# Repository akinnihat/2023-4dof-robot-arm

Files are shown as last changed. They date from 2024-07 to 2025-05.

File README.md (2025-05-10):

# 4 DoF Robot Arm (June 2023)


This is a project I made back in 2023, the last year of my undergraduate education, where I designed, constructed and developed control software of a robotic arm with 4 degrees of freedom.

## Design and Construction


The design of the robot arm was made with Fusion360 (except the gripper, I found it on the internet) and converted to URDF format with the help of [fusion2urdf](https://github.com/syuntoku14/fusion2urdf).
In its construction aluminium with 2mm thickness and 3D printing (PLA, yellow parts in the image above) were used.

## Circuit Design and Electronics


In the electronics of the robot arm:
  - 4 NEMA 17 stepper motors,
  - 4 A4988 stepper motor drivers,
  - 4 100V 100μF capacitors,
  - 2 MG995 servo motors (for gripper control),
  - A power distribution board with 12V and 5V outputs,
  - A 14.8V Li-Po baterry, 
  - Arduino UNO,
  - A laptop was used as the main control computer (originally a Jetson NANO was planned).

## Software and Control


[ROS Noetic](http://wiki.ros.org/noetic) was used on the main computer, [RViz](http://wiki.ros.org/rviz) was used as the control interface and [MoveIt!](https://moveit.ros.org/) was used for kinematics and motion planning. In Arduino, [AccelStepper](https://github.com/waspinator/AccelStepper) was used for stepper motor control and [ros_lib](http://wiki.ros.org/rosserial_arduino/Tutorials/Arduino%20IDE%20Setup) (rosserial) was used for serial communication with ROS.

Installation of ROS Noetic:
```
sudo apt install ros-noetic-desktop
```
Installation of catkin and related build tools:
```
sudo apt install ros-noetic-catkin pyhton3-catkin-tools python3-osrf-pycommon
```
Installation of MoveIt!:
```
sudo apt install ros-noetic-moveit
```
Installation of rosserial for communication between ROS with Arduino over serial (see [ros_lib](http://wiki.ros.org/rosserial_arduino/Tutorials/Arduino%20IDE%20Setup) for Arduino IDE setup for rosserial):
```
sudo apt install ros-noetic-rosserial
sudo apt install ros-noetic-rosserial-arduino
```
Creation of catkin workspace:
```
mkdir catkin-ws
```
Launch of MoveIt! Setup Assistant for robot arm configuration:
```
roslaunch moveit_setup-assistant setup_assistant.launch
```


After configuration of the robot arm, launch of MoveIt! move_group, robot arm hardware interface and serial comminication with Arduino:
```
roslaunch arm_moveit_config move_group.launch
rosrun arm_hardware arm_hardware_node
rosrun rosserial_python serial_node.py _port:=/dev_ttyUSB0 _baud:=115200
```


## Pick and Place

https://github.com/user-attachments/assets/624f2628-760b-4fc2-ad30-154f14537334

## Additional Notes
Some of the flaws made during the development of the project and the points that could have been done better are briefly as follows:
  - Incorrect load capacity calculation and kinematics calculation at the beginning
  - Non-functional 2nd DoF due to design and manufacturing defects
  - No precise control of stepper motors due to lack of feedback mechanism

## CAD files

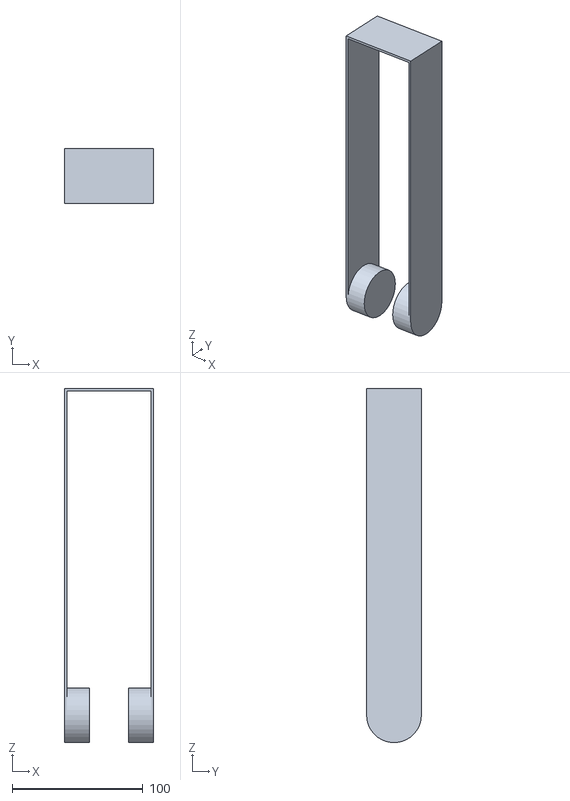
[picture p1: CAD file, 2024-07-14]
catkin_ws/src/arm_description/meshes/D3_1.stl
68.0 x 42.0 x 270.9

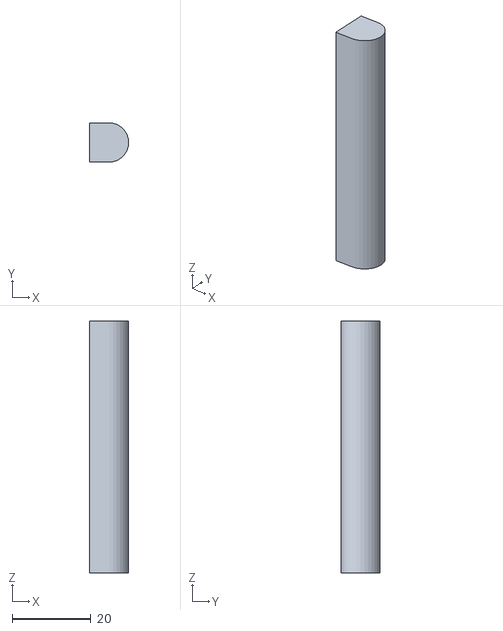
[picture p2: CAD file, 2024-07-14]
catkin_ws/src/arm_description/meshes/Finger_1_1.stl
10.0 x 10.0 x 64.0

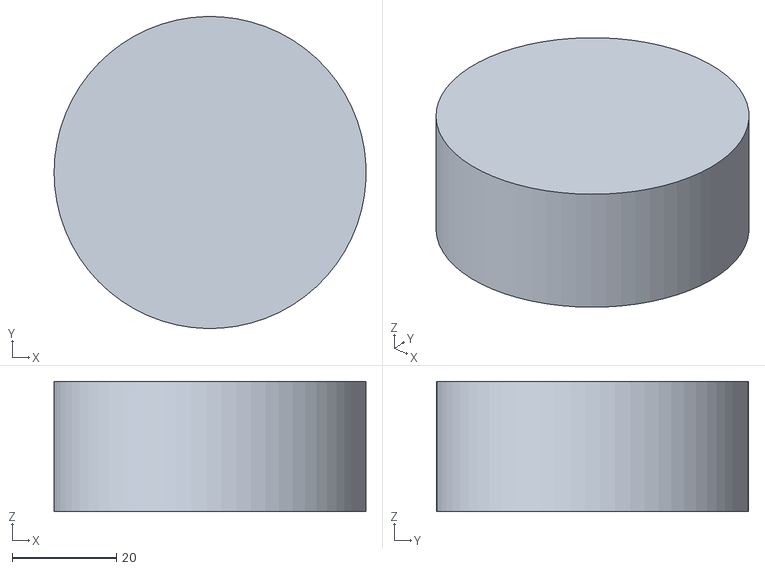
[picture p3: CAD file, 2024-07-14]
catkin_ws/src/arm_description/meshes/base_link.stl
60.0 x 60.0 x 25.0

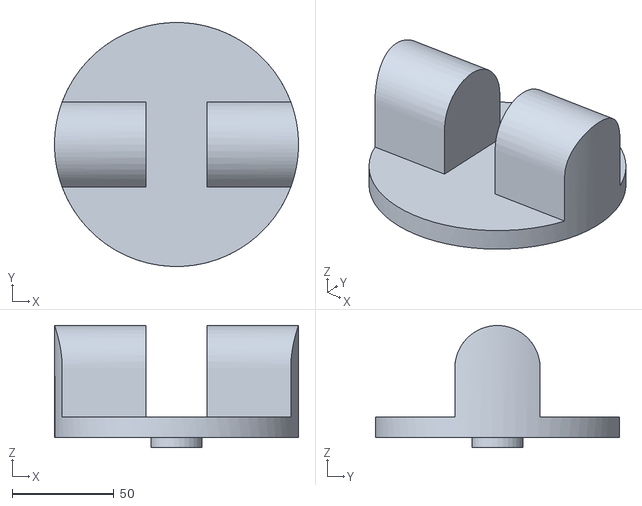
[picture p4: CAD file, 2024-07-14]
catkin_ws/src/arm_description/meshes/Platform_1.stl
120.0 x 120.0 x 60.0

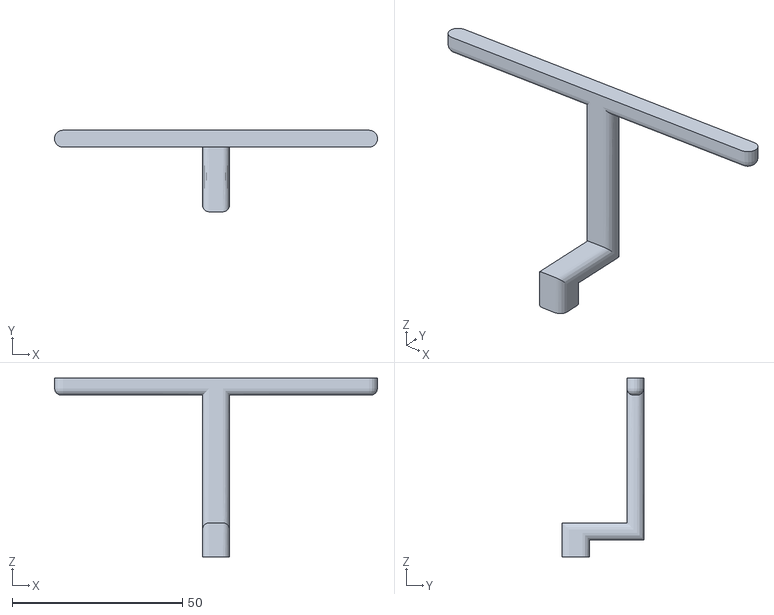
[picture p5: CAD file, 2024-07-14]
catkin_ws/src/arm_description/meshes/D4_1.stl
94.9 x 24.0 x 52.5

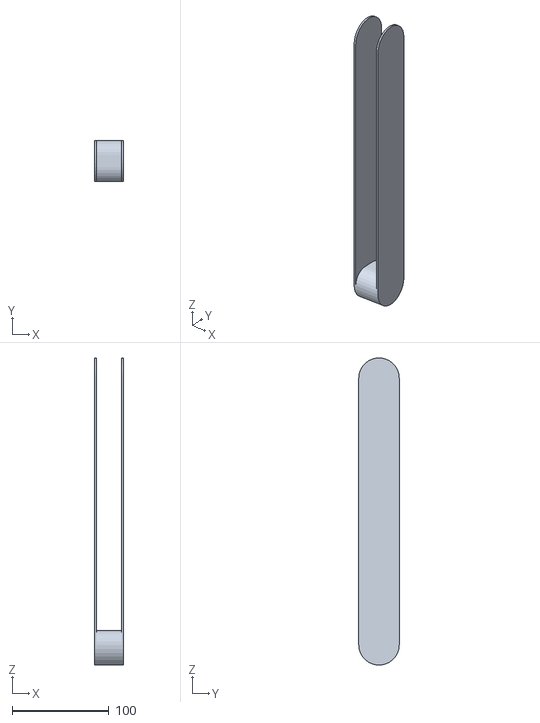
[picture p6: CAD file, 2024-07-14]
catkin_ws/src/arm_description/meshes/D2_1.stl
30.0 x 42.0 x 317.8

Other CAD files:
catkin_ws/src/arm_description/meshes/Finger_2_1.stl

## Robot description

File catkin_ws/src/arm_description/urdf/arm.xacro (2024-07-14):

<?xml version="1.0" ?>
<robot name="arm" xmlns:xacro="http://www.ros.org/wiki/xacro">

<xacro:include filename="$(find arm_description)/urdf/materials.xacro" />
<xacro:include filename="$(find arm_description)/urdf/arm.trans" />
<xacro:include filename="$(find arm_description)/urdf/arm.gazebo" />




<link name="base_link">
  <inertial>
    <origin xyz="0.0 0.0 0.0125" rpy="0 0 0"/>
    <mass value="0.5548838024402973"/>
    <inertia ixx="0.000154" iyy="0.000154" izz="0.00025" ixy="-0.0" iyz="0.0" ixz="0.0"/>
  </inertial>
  <visual>
    <origin xyz="0 0 0" rpy="0 0 0"/>
    <geometry>
      <mesh filename="package://arm_description/meshes/base_link.stl" scale="0.001 0.001 0.001"/>
    </geometry>
    <material name="silver"/>
  </visual>
  <collision>
    <origin xyz="0 0 0" rpy="0 0 0"/>
    <geometry>
      <mesh filename="package://arm_description/meshes/base_link.stl" scale="0.001 0.001 0.001"/>
    </geometry>
  </collision>
</link>

<link name="Platform_1">
  <inertial>
    <origin xyz="1.2106877832099407e-14 8.586438178793906e-18 0.024342559907098243" rpy="0 0 0"/>
    <mass value="2.0787238143023408"/>
    <inertia ixx="0.00147" iyy="0.003108" izz="0.003539" ixy="-0.0" iyz="0.0" ixz="0.0"/>
  </inertial>
  <visual>
    <origin xyz="-0.0 -0.0 -0.025" rpy="0 0 0"/>
    <geometry>
      <mesh filename="package://arm_description/meshes/Platform_1.stl" scale="0.001 0.001 0.001"/>
    </geometry>
    <material name="silver"/>
  </visual>
  <collision>
    <origin xyz="-0.0 -0.0 -0.025" rpy="0 0 0"/>
    <geometry>
      <mesh filename="package://arm_description/meshes/Platform_1.stl" scale="0.001 0.001 0.001"/>
    </geometry>
  </collision>
</link>

<link name="D2_1">
  <inertial>
    <origin xyz="0.015 0.0 0.08469568327292498" rpy="0 0 0"/>
    <mass value="0.6577489881478827"/>
    <inertia ixx="0.006402" iyy="0.006409" izz="0.000181" ixy="-0.0" iyz="-0.0" ixz="-0.0"/>
  </inertial>
  <visual>
    <origin xyz="0.015 -0.0 -0.0625" rpy="0 0 0"/>
    <geometry>
      <mesh filename="package://arm_description/meshes/D2_1.stl" scale="0.001 0.001 0.001"/>
    </geometry>
    <material name="silver"/>
  </visual>
  <collision>
    <origin xyz="0.015 -0.0 -0.0625" rpy="0 0 0"/>
    <geometry>
      <mesh filename="package://arm_description/meshes/D2_1.stl" scale="0.001 0.001 0.001"/>
    </geometry>
  </collision>
</link>

<link name="D3_1">
  <inertial>
    <origin xyz="0.014999999999999958 -1.1804267164782249e-17 0.06749406762008453" rpy="0 0 0"/>
    <mass value="0.7634276110018746"/>
    <inertia ixx="0.006149" iyy="0.006661" izz="0.000708" ixy="-0.0" iyz="-0.0" ixz="-0.0"/>
  </inertial>
  <visual>
    <origin xyz="0.015 0.0 -0.3385" rpy="0 0 0"/>
    <geometry>
      <mesh filename="package://arm_description/meshes/D3_1.stl" scale="0.001 0.001 0.001"/>
    </geometry>
    <material name="silver"/>
  </visual>
  <collision>
    <origin xyz="0.015 0.0 -0.3385" rpy="0 0 0"/>
    <geometry>
      <mesh filename="package://arm_description/meshes/D3_1.stl" scale="0.001 0.001 0.001"/>
    </geometry>
  </collision>
</link>

<link name="D4_1">
  <inertial>
    <origin xyz="9.723077481125942e-17 0.01461192581321165 0.03300377103466645" rpy="0 0 0"/>
    <mass value="0.03728803268567669"/>
    <inertia ixx="1.5e-05" iyy="2.6e-05" izz="1.4e-05" ixy="0.0" iyz="-3e-06" ixz="0.0"/>
  </inertial>
  <visual>
    <origin xyz="-0.0 -0.0 -0.5885" rpy="0 0 0"/>
    <geometry>
      <mesh filename="package://arm_description/meshes/D4_1.stl" scale="0.001 0.001 0.001"/>
    </geometry>
    <material name="silver"/>
  </visual>
  <collision>
    <origin xyz="-0.0 -0.0 -0.5885" rpy="0 0 0"/>
    <geometry>
      <mesh filename="package://arm_description/meshes/D4_1.stl" scale="0.001 0.001 0.001"/>
    </geometry>
  </collision>
</link>

<link name="Finger_1_1">
  <inertial>
    <origin xyz="-0.005466749294592968 -6.938893903907228e-18 0.03199999999999992" rpy="0 0 0"/>
    <mass value="0.044849201864543935"/>
    <inertia ixx="1.6e-05" iyy="1.6e-05" izz="1e-06" ixy="-0.0" iyz="-0.0" ixz="0.0"/>
  </inertial>
  <visual>
    <origin xyz="-0.0475 -0.0175 -0.641" rpy="0 0 0"/>
    <geometry>
      <mesh filename="package://arm_description/meshes/Finger_1_1.stl" scale="0.001 0.001 0.001"/>
    </geometry>
    <material name="silver"/>
  </visual>
  <collision>
    <origin xyz="-0.0475 -0.0175 -0.641" rpy="0 0 0"/>
    <geometry>
      <mesh filename="package://arm_description/meshes/Finger_1_1.stl" scale="0.001 0.001 0.001"/>
    </geometry>
  </collision>
</link>

<link name="Finger_2_1">
  <inertial>
    <origin xyz="0.005466749294592975 -6.938893903907228e-18 0.03199999999999992" rpy="0 0 0"/>
    <mass value="0.044849201864543935"/>
    <inertia ixx="1.6e-05" iyy="1.6e-05" izz="1e-06" ixy="0.0" iyz="-0.0" ixz="0.0"/>
  </inertial>
  <visual>
    <origin xyz="0.0475 -0.0175 -0.641" rpy="0 0 0"/>
    <geometry>
      <mesh filename="package://arm_description/meshes/Finger_2_1.stl" scale="0.001 0.001 0.001"/>
    </geometry>
    <material name="silver"/>
  </visual>
  <collision>
    <origin xyz="0.0475 -0.0175 -0.641" rpy="0 0 0"/>
    <geometry>
      <mesh filename="package://arm_description/meshes/Finger_2_1.stl" scale="0.001 0.001 0.001"/>
    </geometry>
  </collision>
</link>

<joint name="D1" type="continuous">
  <origin xyz="0.0 0.0 0.025" rpy="0 0 0"/>
  <parent link="base_link"/>
  <child link="Platform_1"/>
  <axis xyz="0.0 0.0 1.0"/>
</joint>

<joint name="D2" type="fixed">
  <origin xyz="-0.015 0.0 0.0375" rpy="0 0 0"/>
  <parent link="Platform_1"/>
  <child link="D2_1"/>
</joint>

<joint name="D3" type="continuous">
  <origin xyz="0.0 -0.0 0.276" rpy="0 0 0"/>
  <parent link="D2_1"/>
  <child link="D3_1"/>
  <axis xyz="-1.0 0.0 0.0"/>
</joint>

<joint name="D4" type="continuous">
  <origin xyz="0.015 0.0 0.25" rpy="0 0 0"/>
  <parent link="D3_1"/>
  <child link="D4_1"/>
  <axis xyz="0.0 0.0 1.0"/>
</joint>

<joint name="G1" type="continuous">
  <origin xyz="0.0475 0.0175 0.0525" rpy="0 0 0"/>
  <parent link="D4_1"/>
  <child link="Finger_1_1"/>
  <axis xyz="0.0 1.0 0.0"/>
  <limit upper="0.0" lower="0.0" effort="100" velocity="100"/>
</joint>

<joint name="G2" type="continuous">
  <origin xyz="-0.0475 0.0175 0.0525" rpy="0 0 0"/>
  <parent link="D4_1"/>
  <child link="Finger_2_1"/>
  <axis xyz="0.0 1.0 0.0"/>
  <limit upper="0.0" lower="0.0" effort="100" velocity="100"/>
</joint>

</robot>

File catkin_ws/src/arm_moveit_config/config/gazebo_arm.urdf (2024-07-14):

<?xml version="1.0" ?>
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
<robot name="arm">
    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
    <link name="base_link">
        <inertial>
            <origin rpy="0 0 0" xyz="0.0 0.0 0.0125" />
            <mass value="0.5548838024402973" />
            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
        </inertial>
        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
    </link>
    <link name="Platform_1">
        <inertial>
            <origin rpy="0 0 0" xyz="1.2106877832099407e-14 8.586438178793906e-18 0.024342559907098243" />
            <mass value="2.0787238143023408" />
            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
        </inertial>
        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
    </link>
    <link name="D2_1">
        <inertial>
            <origin rpy="0 0 0" xyz="0.015 0.0 0.08469568327292498" />
            <mass value="0.6577489881478827" />
            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
        </inertial>
        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
    </link>
    <link name="D3_1">
        <inertial>
            <origin rpy="0 0 0" xyz="0.014999999999999958 -1.1804267164782249e-17 0.06749406762008453" />
            <mass value="0.7634276110018746" />
            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
        </inertial>
        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
    </link>
    <link name="D4_1">
        <inertial>
            <origin rpy="0 0 0" xyz="9.723077481125942e-17 0.01461192581321165 0.03300377103466645" />
            <mass value="0.03728803268567669" />
            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
        </inertial>
        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
    </link>
    <link name="Finger_1_1">
        <inertial>
            <origin rpy="0 0 0" xyz="-0.005466749294592968 -6.938893903907228e-18 0.03199999999999992" />
            <mass value="0.044849201864543935" />
            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
        </inertial>
        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
    </link>
    <link name="Finger_2_1">
        <inertial>
            <origin rpy="0 0 0" xyz="0.005466749294592975 -6.938893903907228e-18 0.03199999999999992" />
            <mass value="0.044849201864543935" />
            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
        </inertial>
        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
    </link>
    <joint name="D1" type="continuous">
        <origin rpy="0 0 0" xyz="0.0 0.0 0.025" />
        <parent link="base_link" />
        <child link="Platform_1" />
        <axis xyz="0.0 0.0 1.0" />
    </joint>
    <joint name="D2" type="fixed">
        <origin rpy="0 0 0" xyz="-0.015 0.0 0.0375" />
        <parent link="Platform_1" />
        <child link="D2_1" />
    </joint>
    <joint name="D3" type="continuous">
        <origin rpy="0 0 0" xyz="0.0 -0.0 0.276" />
        <parent link="D2_1" />
        <child link="D3_1" />
        <axis xyz="-1.0 0.0 0.0" />
    </joint>
    <joint name="D4" type="continuous">
        <origin rpy="0 0 0" xyz="0.015 0.0 0.25" />
        <parent link="D3_1" />
        <child link="D4_1" />
        <axis xyz="0.0 0.0 1.0" />
    </joint>
    <joint name="G1" type="continuous">
        <origin rpy="0 0 0" xyz="0.0475 0.0175 0.0525" />
        <parent link="D4_1" />
        <child link="Finger_1_1" />
        <axis xyz="0.0 1.0 0.0" />
        <limit effort="100" lower="0.0" upper="0.0" velocity="100" />
    </joint>
    <joint name="G2" type="continuous">
        <origin rpy="0 0 0" xyz="-0.0475 0.0175 0.0525" />
        <parent link="D4_1" />
        <child link="Finger_2_1" />
        <axis xyz="0.0 1.0 0.0" />
        <limit effort="100" lower="0.0" upper="0.0" velocity="100" />
    </joint>
</robot>

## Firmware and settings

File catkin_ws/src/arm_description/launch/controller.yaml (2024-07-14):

arm_controller:
  # Publish all joint states -----------------------------------
  joint_state_controller:
    type: joint_state_controller/JointStateController
    publish_rate: 50

  # Position Controllers --------------------------------------
  D1_position_controller:
    type: effort_controllers/JointPositionController
    joint: D1
    pid: {p: 100.0, i: 0.01, d: 10.0}
  D2_position_controller:
    type: effort_controllers/JointPositionController
    joint: D2
    pid: {p: 100.0, i: 0.01, d: 10.0}
  D3_position_controller:
    type: effort_controllers/JointPositionController
    joint: D3
    pid: {p: 100.0, i: 0.01, d: 10.0}
  D4_position_controller:
    type: effort_controllers/JointPositionController
    joint: D4
    pid: {p: 100.0, i: 0.01, d: 10.0}
  Slider 5_position_controller:
    type: effort_controllers/JointPositionController
    joint: Slider 5
    pid: {p: 100.0, i: 0.01, d: 10.0}
  Slider 6_position_controller:
    type: effort_controllers/JointPositionController
    joint: Slider 6
    pid: {p: 100.0, i: 0.01, d: 10.0}

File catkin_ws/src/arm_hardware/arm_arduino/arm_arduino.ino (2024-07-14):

#include <ros.h>
#include <Arduino.h>
#include <arm_custom_interfaces/ArmJointState.h>
#include <AccelStepper.h>
#include <MultiStepper.h>
#include <Servo.h>


const float rad_to_deg_to_stp = 200/PI;  //pi*0.9

int step_1 = 0;
int step_2_1 = 0;
int step_2_2 = 0;
int step_3 = 0;
int degree = 0;

AccelStepper stepper_1(AccelStepper::FULL2WIRE, 2, 3);
AccelStepper stepper_2_1(AccelStepper::FULL2WIRE, 4, 5);
AccelStepper stepper_2_2(AccelStepper::FULL2WIRE, 6, 7);
AccelStepper stepper_3(AccelStepper::FULL2WIRE, 8, 9);
MultiStepper steppers;

Servo servo_d4;
Servo gripper;

bool is_gripper_active = false;
bool new_state = false;
int motor_steps[4] = {0, 0, 0, 0};
ros::NodeHandle nh;

void callback_gripper(const arm_custom_interfaces::ArmJointState& grpr_cmds)
{
  is_gripper_active = grpr_cmds.is_gripper_active;
}

void callback_arm(const arm_custom_interfaces::ArmJointState& arm_cmds)
{
  new_state = true;
  motor_steps[0] = 6.2*(arm_cmds.position_d1 * rad_to_deg_to_stp);  // Radian >> Degree >> Step (1 Step = 1.8 Degree)
  motor_steps[1] = arm_cmds.position_d2 * rad_to_deg_to_stp;
  motor_steps[2] = 19*(arm_cmds.position_d3 * rad_to_deg_to_stp);
  motor_steps[3] = arm_cmds.position_d4 * rad_to_deg_to_stp;
  degree = arm_cmds.position_d4 * (180/PI);
  //is_gripper_active = arm_cmds.is_gripper_active;

  //motor_steps[0] = 264;  // Radian >> Degree >> Step (1 Step = 1.8 Degree)
  //motor_steps[2] = 0;

}

ros::Subscriber<arm_custom_interfaces::ArmJointState> arm_sub("joint_steps", &callback_arm);
ros::Subscriber<arm_custom_interfaces::ArmJointState> gripper_sub("gripper_activation", &callback_gripper); 

void setup() {
  
  nh.getHardware()->setBaud(115200);
  nh.initNode();
  nh.subscribe(arm_sub);
  nh.subscribe(gripper_sub);


  stepper_1.setMaxSpeed(200.0);
  stepper_1.setAcceleration(100.0);

  stepper_2_1.setMaxSpeed(0.0);
  stepper_2_1.setAcceleration(0.0);

  stepper_2_2.setMaxSpeed(0.0);
  stepper_2_2.setAcceleration(0.0);

  stepper_3.setMaxSpeed(200.0);
  stepper_3.setAcceleration(75.0);

  steppers.addStepper(stepper_1);
  //steppers.addStepper(stepper_2_1);
  //steppers.addStepper(stepper_2_2);
  steppers.addStepper(stepper_3);

  servo_d4.attach(10);
  gripper.attach(11);
  //Serial.begin(9600);
  gripper.write(0);


}

void loop() {


  if (new_state == true) 
  {
    
    long int to_motors[2] = {motor_steps[0], -motor_steps[2]};

    int last_p1 = motor_steps[0];
    //stepper_1.moveTo(-motor_steps[0]);

    //stepper_1.run();
    //stepper_3.run();
    steppers.moveTo(to_motors);

    nh.spinOnce();
    //steppers.run();
    steppers.runSpeedToPosition(); 
    
    //servo_d4.write(degree);


  }

  if (is_gripper_active == true)
  {
    gripper.write(180);
  } else { gripper.write(0); }

  new_state = false; 
  nh.spinOnce();
  delay(1);

}

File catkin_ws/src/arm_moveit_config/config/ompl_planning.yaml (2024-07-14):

planner_configs:
  AnytimePathShortening:
    type: geometric::AnytimePathShortening
    shortcut: true  # Attempt to shortcut all new solution paths
    hybridize: true  # Compute hybrid solution trajectories
    max_hybrid_paths: 24  # Number of hybrid paths generated per iteration
    num_planners: 4  # The number of default planners to use for planning
    planners: ""  # A comma-separated list of planner types (e.g., "PRM,EST,RRTConnect"Optionally, planner parameters can be passed to change the default:"PRM[max_nearest_neighbors=5],EST[goal_bias=.5],RRT[range=10. goal_bias=.1]"
  SBL:
    type: geometric::SBL
    range: 0.0  # Max motion added to tree. ==> maxDistance_ default: 0.0, if 0.0, set on setup()
  EST:
    type: geometric::EST
    range: 0.0  # Max motion added to tree. ==> maxDistance_ default: 0.0, if 0.0 setup()
    goal_bias: 0.05  # When close to goal select goal, with this probability. default: 0.05
  LBKPIECE:
    type: geometric::LBKPIECE
    range: 0.0  # Max motion added to tree. ==> maxDistance_ default: 0.0, if 0.0, set on setup()
    border_fraction: 0.9  # Fraction of time focused on boarder default: 0.9
    min_valid_path_fraction: 0.5  # Accept partially valid moves above fraction. default: 0.5
  BKPIECE:
    type: geometric::BKPIECE
    range: 0.0  # Max motion added to tree. ==> maxDistance_ default: 0.0, if 0.0, set on setup()
    border_fraction: 0.9  # Fraction of time focused on boarder default: 0.9
    failed_expansion_score_factor: 0.5  # When extending motion fails, scale score by factor. default: 0.5
    min_valid_path_fraction: 0.5  # Accept partially valid moves above fraction. default: 0.5
  KPIECE:
    type: geometric::KPIECE
    range: 0.0  # Max motion added to tree. ==> maxDistance_ default: 0.0, if 0.0, set on setup()
    goal_bias: 0.05  # When close to goal select goal, with this probability. default: 0.05
    border_fraction: 0.9  # Fraction of time focused on boarder default: 0.9 (0.0,1.]
    failed_expansion_score_factor: 0.5  # When extending motion fails, scale score by factor. default: 0.5
    min_valid_path_fraction: 0.5  # Accept partially valid moves above fraction. default: 0.5
  RRT:
    type: geometric::RRT
    range: 0.0  # Max motion added to tree. ==> maxDistance_ default: 0.0, if 0.0, set on setup()
    goal_bias: 0.05  # When close to goal select goal, with this probability? default: 0.05
  RRTConnect:
    type: geometric::RRTConnect
    range: 0.0  # Max motion added to tree. ==> maxDistance_ default: 0.0, if 0.0, set on setup()
  RRTstar:
    type: geometric::RRTstar
    range: 0.0  # Max motion added to tree. ==> maxDistance_ default: 0.0, if 0.0, set on setup()
    goal_bias: 0.05  # When close to goal select goal, with this probability? default: 0.05
    delay_collision_checking: 1  # Stop collision checking as soon as C-free parent found. default 1
  TRRT:
    type: geometric::TRRT
    range: 0.0  # Max motion added to tree. ==> maxDistance_ default: 0.0, if 0.0, set on setup()
    goal_bias: 0.05  # When close to goal select goal, with this probability? default: 0.05
    max_states_failed: 10  # when to start increasing temp. default: 10
    temp_change_factor: 2.0  # how much to increase or decrease temp. default: 2.0
    min_temperature: 10e-10  # lower limit of temp change. default: 10e-10
    init_temperature: 10e-6  # initial temperature. default: 10e-6
    frountier_threshold: 0.0  # dist new state to nearest neighbor to disqualify as frontier. default: 0.0 set in setup()
    frountierNodeRatio: 0.1  # 1/10, or 1 nonfrontier for every 10 frontier. default: 0.1
    k_constant: 0.0  # value used to normalize expresssion. default: 0.0 set in setup()
  PRM:
    type: geometric::PRM
    max_nearest_neighbors: 10  # use k nearest neighbors. default: 10
  PRMstar:
    type: geometric::PRMstar
  FMT:
    type: geometric::FMT
    num_samples: 1000  # number of states that the planner should sample. default: 1000
    radius_multiplier: 1.1  # multiplier used for the nearest neighbors search radius. default: 1.1
    nearest_k: 1  # use Knearest strategy. default: 1
    cache_cc: 1  # use collision checking cache. default: 1
    heuristics: 0  # activate cost to go heuristics. default: 0
    extended_fmt: 1  # activate the extended FMT*: adding new samples if planner does not finish successfully. default: 1
  BFMT:
    type: geometric::BFMT
    num_samples: 1000  # number of states that the planner should sample. default: 1000
    radius_multiplier: 1.0  # multiplier used for the nearest neighbors search radius. default: 1.0
    nearest_k: 1  # use the Knearest strategy. default: 1
    balanced: 0  # exploration strategy: balanced true expands one tree every iteration. False will select the tree with lowest maximum cost to go. default: 1
    optimality: 1  # termination strategy: optimality true finishes when the best possible path is found. Otherwise, the algorithm will finish when the first feasible path is found. default: 1
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

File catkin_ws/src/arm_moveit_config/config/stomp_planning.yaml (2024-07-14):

stomp/arm_group:
  group_name: arm_group
  optimization:
    num_timesteps: 60
    num_iterations: 40
    num_iterations_after_valid: 0
    num_rollouts: 30
    max_rollouts: 30
    initialization_method: 1  # [1 : LINEAR_INTERPOLATION, 2 : CUBIC_POLYNOMIAL, 3 : MININUM_CONTROL_COST]
    control_cost_weight: 0.0
  task:
    noise_generator:
      - class: stomp_moveit/NormalDistributionSampling
        stddev: [0.05, 0.05, 0.05]
    cost_functions:
      - class: stomp_moveit/CollisionCheck
        collision_penalty: 1.0
        cost_weight: 1.0
        kernel_window_percentage: 0.2
        longest_valid_joint_move: 0.05
    noisy_filters:
      - class: stomp_moveit/JointLimits
        lock_start: True
        lock_goal: True
      - class: stomp_moveit/MultiTrajectoryVisualization
        line_width: 0.02
        rgb: [255, 255, 0]
        marker_array_topic: stomp_trajectories
        marker_namespace: noisy
    update_filters:
      - class: stomp_moveit/PolynomialSmoother
        poly_order: 6
      - class: stomp_moveit/TrajectoryVisualization
        line_width: 0.05
        rgb: [0, 191, 255]
        error_rgb: [255, 0, 0]
        publish_intermediate: True
        marker_topic: stomp_trajectory
        marker_namespace: optimized
stomp/gripper_group:
  group_name: gripper_group
  optimization:
    num_timesteps: 60
    num_iterations: 40
    num_iterations_after_valid: 0
    num_rollouts: 30
    max_rollouts: 30
    initialization_method: 1  # [1 : LINEAR_INTERPOLATION, 2 : CUBIC_POLYNOMIAL, 3 : MININUM_CONTROL_COST]
    control_cost_weight: 0.0
  task:
    noise_generator:
      - class: stomp_moveit/NormalDistributionSampling
        stddev: [0.05]
    cost_functions:
      - class: stomp_moveit/CollisionCheck
        collision_penalty: 1.0
        cost_weight: 1.0
        kernel_window_percentage: 0.2
        longest_valid_joint_move: 0.05
    noisy_filters:
      - class: stomp_moveit/JointLimits
        lock_start: True
        lock_goal: True
      - class: stomp_moveit/MultiTrajectoryVisualization
        line_width: 0.02
        rgb: [255, 255, 0]
        marker_array_topic: stomp_trajectories
        marker_namespace: noisy
    update_filters:
      - class: stomp_moveit/PolynomialSmoother
        poly_order: 6
      - class: stomp_moveit/TrajectoryVisualization
        line_width: 0.05
        rgb: [0, 191, 255]
        error_rgb: [255, 0, 0]
        publish_intermediate: True
        marker_topic: stomp_trajectory
        marker_namespace: optimized
